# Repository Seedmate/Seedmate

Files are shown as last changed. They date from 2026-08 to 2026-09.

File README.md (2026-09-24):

# SeedMate

SeedMate is a PIC32MM-based offline device for generating, loading, transforming, splitting, merging, displaying, and exporting BIP39-compatible seed data.

www.seedmate.net

Status: Tested and production-ready. However, unexpected bugs may still occur.

## Features

- Offline seed handling
- Entropy capture from multiple sources and multiple conversion methods
- BIP39 word-based workflows
- SeedXOR operations
- Shamir Secret Sharing over BIP39
- BIP85 derivation
- QR export
- SD card storage/export
- TFT display and button-driven interface

## Hardware target - See HW folfer

This project targets a PIC32MM-based device with:

- TFT display
- Physical buttons
- SD card interface
- LED blinking

MCU and tools:

- MCU: `PIC32MM0064GPL028`
- Toolchain: `XC32 v4.60`
- IDE / generated files: `MPLAB X / Harmony`

## Project structure

```text
src/
  main.c
  SPI.*
  TFT.*
  SHA256.*
  SHA512.*
  words.h
  SSS/
  SD/
  QRCode-master/
  WjCryptLib-master/
  config/default/    

  ## Build

This project is intended to be built with Microchip tools.

### Requirements

- MPLAB X

- XC32 compiler

- PIC32MM device pack

- Any project-generated files required by Harmony / MPLAB

### Typical build flow

1. Open the project in MPLAB X.

2. Select the correct configuration.

3. Build the project with XC32.

4. Flash the generated firmware to the target board. A Microchip programmer tool is required:
https://www.microchip.com/en-us/development-tool/pg164130

## Programming instructions / firmware update
See https://www.seedmate.net/FW_update.html

## Usage notes

- This device is designed to work offline 

- Do not use phones, cloud notes, or networked systems to store sensitive seed material.

- Review the full workflow yourself before trusting it with real funds.

- Treat QR and SD export paths as sensitive.

- See Security Risks & Guidelines https://www.seedmate.net/security.html

## Security warning

This project handles highly sensitive cryptographic material.

This repository is provided for development, educational, and commercial applications unless explicitly stated otherwise.

## Third-party components

This project includes or references third-party code. See:

- THIRD_PARTY_NOTICES.md

## Roadmap / pending cleanup

## License

This project is licensed under the MIT License.

MIT License

Copyright (c) 2026 Seedmate

Permission is hereby granted, free of charge, to any person obtaining a copy
of this software and associated documentation files (the "Software"), to deal
in the Software without restriction, including without limitation the rights
to use, copy, modify, merge, publish, distribute, sublicense, and/or sell
copies of the Software, and to permit persons to whom the Software is
furnished to do so, subject to the following conditions:

The above copyright notice and this permission notice shall be included in all
copies or substantial portions of the Software.

THE SOFTWARE IS PROVIDED "AS IS", WITHOUT WARRANTY OF ANY KIND, EXPRESS OR
IMPLIED, INCLUDING BUT NOT LIMITED TO THE WARRANTIES OF MERCHANTABILITY,
FITNESS FOR A PARTICULAR PURPOSE AND NONINFRINGEMENT. IN NO EVENT SHALL THE
AUTHORS OR COPYRIGHT HOLDERS BE LIABLE FOR ANY CLAIM, DAMAGES OR OTHER
LIABILITY, WHETHER IN AN ACTION OF CONTRACT, TORT OR OTHERWISE, ARISING FROM,
OUT OF OR IN CONNECTION WITH THE SOFTWARE OR THE USE OR OTHER DEALINGS IN THE
SOFTWARE.

## Author

Seedmate

## Disclaimer

Use at your own risk. The authors provide no warranty of correctness, fitness, or security.

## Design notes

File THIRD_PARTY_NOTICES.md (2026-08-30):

**THIRD_PARTY_NOTICES.md**
```md
# Third-Party Notices

This project includes, vendors, or references third-party components.

## Important

## 1. WjCryptLib

- **Directory:** `src/WjCryptLib-master/`
- **Project:** `WjCryptLib`
- **Upstream:** `https://github.com/WaterJuice/WjCryptLib`
- **Used for:** SHA256 for checksum calculation
- **Used for:** SHA512 for BIP85 derivation
- **License:** `UNLICENSE`
- **Copyright:** `Public Domain (Author: WaterJuice)`

---

## 2. QRCode library

- **Directory:** `src/QRCode-master/`
- **Project:** `QRCode`
- **Upstream:** `https://github.com/ricmoo/QRCode`
- **Used for:** QR code generation
 * Copyright (c) 2017 Richard Moore     (https://github.com/ricmoo/QRCode)
 * Copyright (c) 2017 Project Nayuki    (https://www.nayuki.io/page/qr-code-generator-library)
 *
 * Permission is hereby granted, free of charge, to any person obtaining a copy
 * of this software and associated documentation files (the "Software"), to deal
 * in the Software without restriction, including without limitation the rights
 * to use, copy, modify, merge, publish, distribute, sublicense, and/or sell
 * copies of the Software, and to permit persons to whom the Software is
 * furnished to do so, subject to the following conditions:
 *
 * The above copyright notice and this permission notice shall be included in
 * all copies or substantial portions of the Software. 

## 3. Shamir Secret Share

- **Directory / file:** `src/SSS`
- **Project:** `trezor-firmware`
- **Upstream:** `https://github.com/trezor/trezor-firmware/blob/main/crypto/`
- **Used for:** `Shamir arithmetics`
 * Implementation of the hazardous parts of the SSS library
 *
 * Copyright (c) 2017 Daan Sprenkels <hello@dsprenkels.com>
 * Copyright (c) 2019 SatoshiLabs
 *
 * Permission is hereby granted, free of charge, to any person obtaining
 * a copy of this software and associated documentation files (the "Software"),
 * to deal in the Software without restriction, including without limitation
 * the rights to use, copy, modify, merge, publish, distribute, sublicense,
 * and/or sell copies of the Software, and to permit persons to whom the
 * Software is furnished to do so, subject to the following conditions:
 *
 * The above copyright notice and this permission notice shall be included
 * in all copies or substantial portions of the Software.

## 4. Microchip-generated or Microchip-provided code

- **Directories / files:**  
  - `src/config/default/`
  - generated startup / peripheral / Harmony-related files
- **Provider:** Microchip Technology Inc.
- **Upstream:** MPLAB X / Harmony / device pack generated content
- **Used for:** platform initialization, peripheral support, device integration
- **License:** `Microchip Restricted License`
- **Copyright:** 2025 Microchip Technology Inc. and its subsidiaries.

---

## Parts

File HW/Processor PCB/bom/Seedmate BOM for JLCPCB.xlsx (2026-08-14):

Comment | Designator | Footprint | Quantity | JLCPCB Part #（optional）
Cap Ceramic 0.1uF 10V X5R 10% SMD 0402 85C Paper T/R | C1, C4, C5, C6, C8, C9 | GRM152R61A104KE19D | 6 | C1525
CAP CER 10UF 25V X5R 0805 | C2, C3, C7, C11 | GRM21BR61E106KA73K | 4 | C15850
CAP CER 470PF 50V X7R 0603 | C10 | C0603C471K5RACTU | 1 | C1620
Diode green | D1 | DY-332SUGD-A3 | 1 | C7470788
Diode blue | D2 | DY-333YD-SN-A3(EL) | 1 | C7470788
Battery holder | J2 | BH-AAA-B5AA005 | 1 | C2979170
push buttons | SW2, SW3, SW4, SW5, SW6, SW7 | K2-6639SP-J4SC-04 | 6 | C191623
RES SMD 10K OHM 1% 1/10W 0603 | R1 | CRCW060310K0FKEA | 1 | C25804
RES SMD 1K OHM 1% 1/10W 0603 | R2 | CRCW06031K00FKEA | 1 | C21190
RES 1K2 OHM 1/8W 1% SMD 0805 | R3, R4 |  | 2
SPDT 300mA 6V | SW1 | K3-1280S-F1 | 1 | C92658
PIC processor | U1 | PIC32MM0064GPL028-ISS | 1 | C81795
IC REG LINEAR 3.3V 500MA SOT23-5 | U2 | MIC5219-3.3YM5-TR | 1 | C29613
1 1x4P 2.54mm 4P Plugin,P=2.54mm Pin Headers ROHS | J3 | 2.54-1*4 | 1 | C5116483

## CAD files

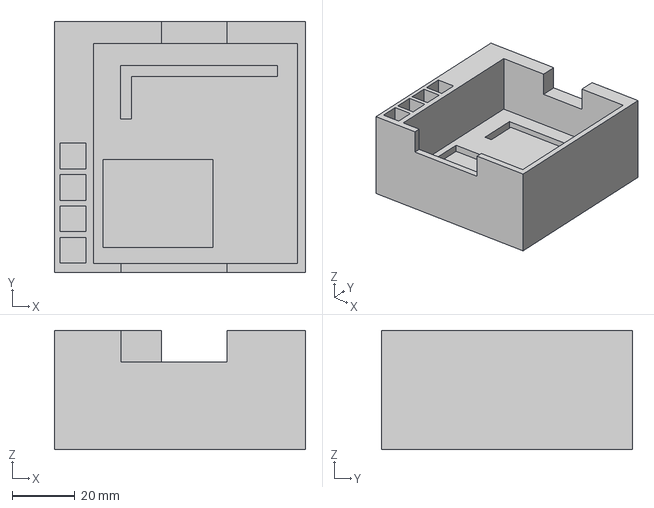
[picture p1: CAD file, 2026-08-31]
HW/Assembly/3D/package.step
80.0 x 80.0 x 38.0 mm

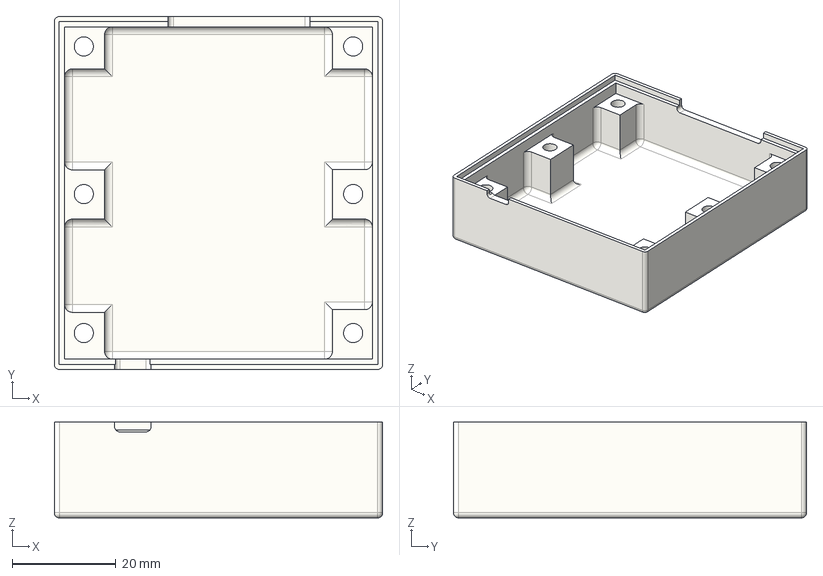
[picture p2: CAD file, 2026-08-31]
HW/Assembly/3D/case_bottom.step
63.4 x 68.2 x 18.5 mm

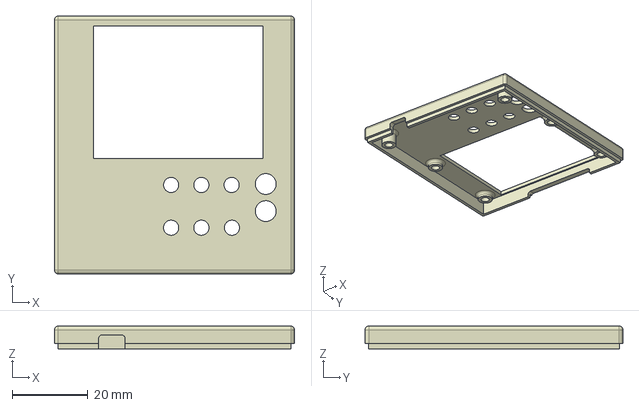
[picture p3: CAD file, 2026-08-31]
HW/Assembly/3D/case_top.step
63.4 x 68.2 x 6.05 mm

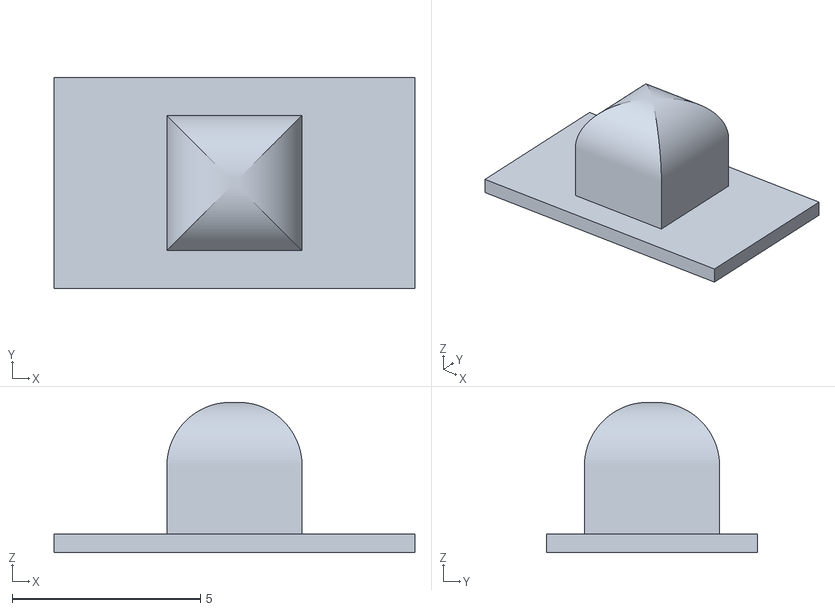
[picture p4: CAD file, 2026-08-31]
HW/Assembly/3D/slide button.stl
9.60 x 5.60 x 4.00

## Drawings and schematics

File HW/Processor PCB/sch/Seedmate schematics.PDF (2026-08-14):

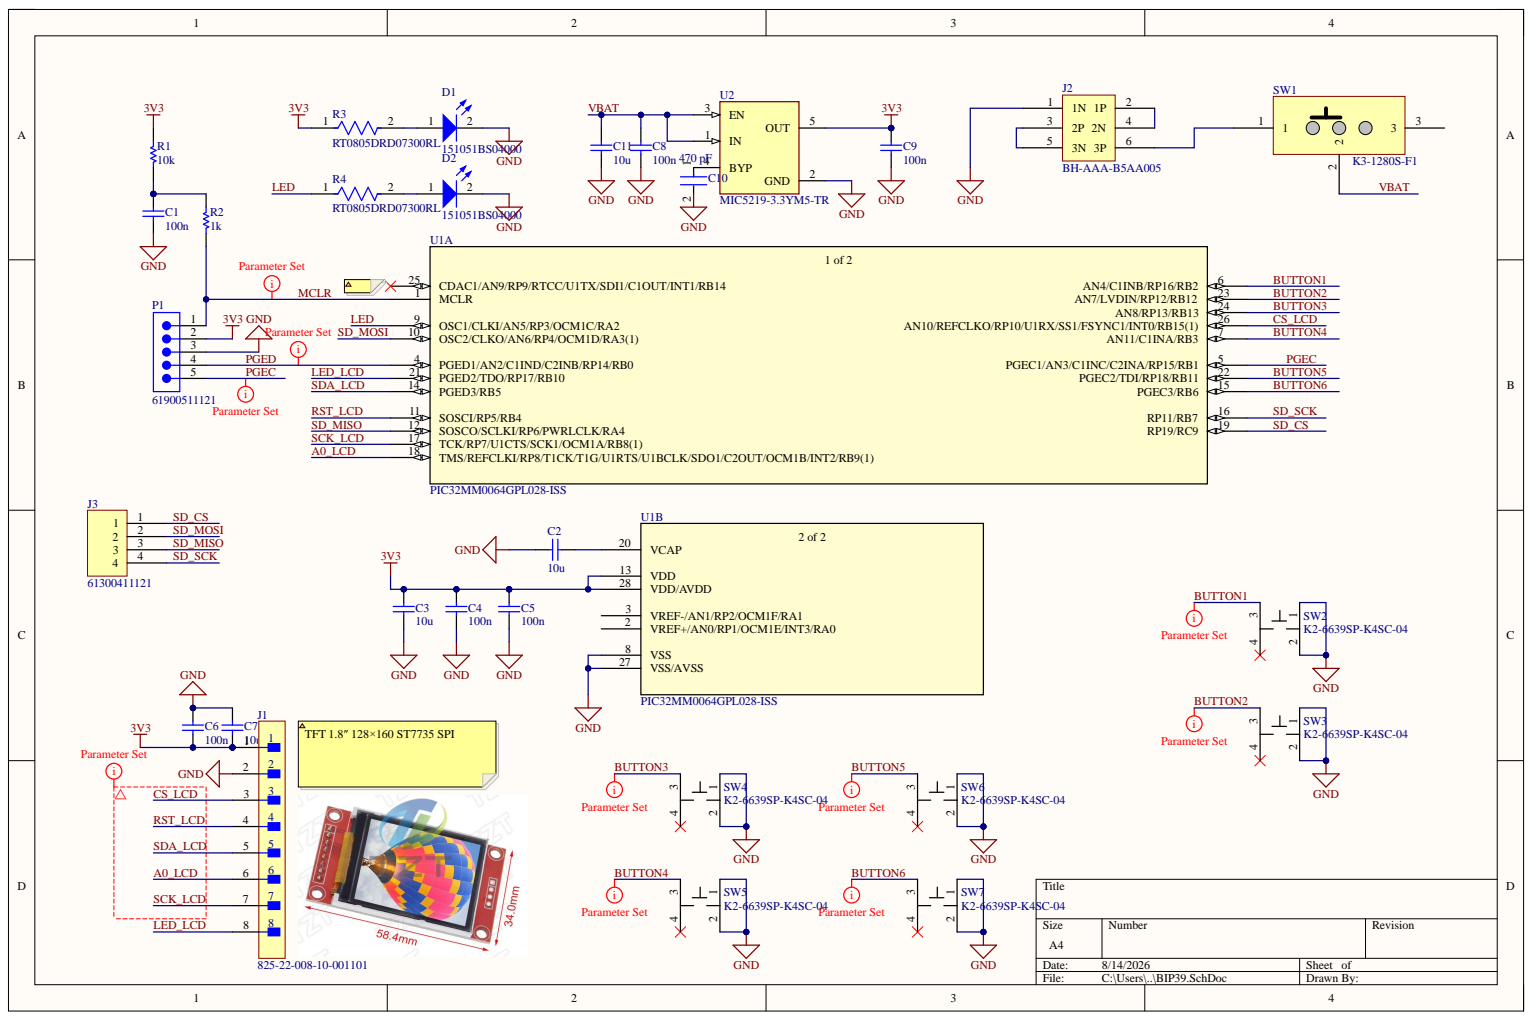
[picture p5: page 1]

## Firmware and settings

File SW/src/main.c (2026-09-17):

/*******************************************************************************
 * Project:     SeedMate
 * File:        main.c
 *
 * Summary:
 *   Main application entry point for the SeedMate firmware.
 *
 * Description:
 *   This firmware runs on a PIC32MM-based platform with TFT display, buttons,
 *   SD card support, QR generation, and entropy capture features. It provides
 *   an offline workflow to create, load, transform, split, merge, display,
 *   and export BIP39-compatible seed data.
 *
 * Main responsibilities:
 *   - Initialize hardware and application services
 *   - Handle user input and screen navigation
 *   - Capture entropy from supported input sources
 *   - Manage seed generation and validation
 *   - Support XOR and Shamir-based operations
 *   - Export data through QR and SD card features
 *
 * Notes:
 *   - This project is intended for offline use
 *   - Security-sensitive data should be handled carefully at all times
 *
 * Author:      Seedmate
 * Date:        17/09/2026
 * Version:     v1.7                               
 * License
 * 
 * This project is licensed under the MIT License.
 * 
 * MIT License
 * 
 * Copyright (c) 2026 Seedmate
 * 
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
 * THE SOFTWARE IS PROVIDED "AS IS", WITHOUT WARRANTY OF ANY KIND, EXPRESS OR
 * IMPLIED, INCLUDING BUT NOT LIMITED TO THE WARRANTIES OF MERCHANTABILITY,
 * FITNESS FOR A PARTICULAR PURPOSE AND NONINFRINGEMENT. IN NO EVENT SHALL THE
 * AUTHORS OR COPYRIGHT HOLDERS BE LIABLE FOR ANY CLAIM, DAMAGES OR OTHER
 * LIABILITY, WHETHER IN AN ACTION OF CONTRACT, TORT OR OTHERWISE, ARISING FROM,
 * OUT OF OR IN CONNECTION WITH THE SOFTWARE OR THE USE OR OTHER DEALINGS IN THE
 * SOFTWARE.
 ******************************************************************************/

// *****************************************************************************
// *****************************************************************************
// Section: Included Files
// *****************************************************************************
// *****************************************************************************

#include <stddef.h>                     // Defines NULL
#include <stdbool.h>                    // Defines true
#include <stdlib.h>                     // Defines EXIT_FAILURE
#include "definitions.h"                // SYS function prototypes
#include "SPI.h"                        // SPI functions
#include "TFT.h"                        // TFT functions
#include "sha256.h"
#include "sha512.h"
//#include "screens.h"
#include "words_opt.h"
#include <string.h>
#include "SSS/shamir.h"
#include "QRCode-master/src/qrcode.h"
#define QR_SCALE 4 // Size of each module in pixels
#define SCREEN_WIDTH 160
#define SCREEN_HEIGHT 128


#define cVersion "v1.7"

#define SD_SCK    PORTBbits.RB7
#define SD_CS     PORTCbits.RC9
#define SD_MISO   PORTAbits.RA4
#define SD_MOSI   PORTAbits.RA3

// Pin mapping
#define LED       PORTAbits.RA2   // CPU activity led

// LCD
#define LED_LCD   PORTBbits.RB10  // TFT backlight control

// Buttons
#define BT1       PORTBbits.RB2   // Button 1
#define BT2       PORTBbits.RB12  // Button 2
#define BT_OK     PORTBbits.RB13  // Button 3
#define BT4       PORTBbits.RB3   // Button 4
#define BT5       PORTBbits.RB11  // Button 5
#define BT6       PORTBbits.RB6   // Button 6


#define cMAIN_n_opt 10
#define cSEED_n_opt 6
#define cSIZE_n_opt 2
#define cOBFUS_n_opt 5
#define cXOR_n_opt 3
#define cSSS_n_opt 2
#define cQR_n_opt 2
#define cSDBLOCK_n_opt 8
#define cSELINPUT_n_opt 2
#define cDICE_MODE_n_opt 2
#define cHASH_MODE_n_opt 2
#define cRESOURCE_n_opt 5
#define cSETTINGS_n_opt 1
#define cSETTINGS_SEEDQR 0
#define cEND_OF_LINE 150
#define cENTROPY_BITS12W 127
#define cENTROPY_BITS24W 255
#define cCARD_MAX_HISTORY 128

bool seedqr_enabled = false;
int settings_pointer = 0;


#define cMAIN_create 0
#define cMAIN_LOAD 1
#define cMAIN_BIP85 2
#define cMAIN_SSS 3
#define cMAIN_XOR 4
#define cMAIN_OBFUS 5
#define cMAIN_MNEM2CARD 6
#define cMAIN_ERASESD 7
#define cMAIN_QR 8 // Resources menu
#define cMAIN_SETTINGS 9

#define cRESOURCE_tutorial 0
#define cRESOURCE_backup 1
#define cRESOURCE_dice_test 2
#define cRESOURCE_wordlist 3
#define cRESOURCE_BINlist 4

#define cOBFUS_SHIFT 0
#define cOBFUS_NOT 1
#define cOBFUS_ADD 2
#define cOBFUS_1WORD_XOR 3
#define cOBFUS_HOWTO 4

#define cSEED_coin 0
#define cSEED_dice 1
#define cSEED_word 2
#define cSEED_cards 3
#define cSEED_timer 4
#define cSEED_triple 5


#define cSIZE_12 0
#define cSIZE_24 1

#define cKEYBOARD 0
#define cFROMSD 1
#define cSD_CHECKSUM_ADDR 64
#define cSD_SIZE_ADDR 65
#define cSD_XOR_ADDR 66 // Key storage offset

#define cLEFT 0
#define cRIGTH 1

#define cADD 0
#define cSUB 1

#define cNOTSAFE 0
#define cSAFE 1

#define cREAD 0
#define cWRITE 1

#define cQRCOMPACT 1

#define  cSPLIT 0
#define  cMERGE 1

// SSS limits
#define  cK_MAX 6 // Max 6th order polynomial
#define  cN_MAX 9 // Max 9 samples

#define INCORRECT_MSG "INCORRECT SET OF WORDS"
#define LOAD_OK "LOAD OK"
#define OK_MSG "OK"

#define SHA512_SIZE 64          // SHA512 output size
#define BLOCK_SIZE 128 // SHA512 block size

// ============================================================================
// Global Menus (Forces the compiler to store pointers strictly in ROM)
// ============================================================================
const char* const menu_main[]     = {"CREATE NEW SEED WORDS", "LOAD SEED WORDS", "BIP85 CHILD SEED", "SHAMIR SECRET SHARE", "SEED WORD XOR", "OBFUSCATION", "MNEMONIC TO CARDS", "ERASE SD", "RESOURCES", "SETTINGS"};
const char* const menu_create[]   = {"THROW COINS", "ROLL DICE", "RANDOM WORD PICK", "DRAW CARDS", "STOPWATCH TEST ONLY", "TRIPLE MNEMONIC"};
const char* const menu_dice[]     = {"RAW ENTROPY BITS", "STRING HASH"};
const char* const menu_hash[]     = {"1-6 mode", "0-5 mode (Keystone)"};
const char* const menu_size[]     = {"12 WORDS", "24 WORDS"};
const char* const menu_qr[]       = {"STANDARD", "COMPACT"};
const char* const menu_xor[]      = {"A XOR B = C", "A XOR B XOR C = D", "A XOR B XOR C XOR D = E"};
const char* const menu_sss[]      = {"SPLIT", "MERGE"};
const char* const menu_input[]    = {"FROM KEYBOARD", "FROM SD"};
const char* const menu_resource[] = {"TUTORIAL", "BACKUP TOOL", "DICE TESTER", "PRINT WORDLIST", "BINARY WORDLIST"};
const char* const menu_obfus[]    = {"CIRCULAR SHIFT", "NOT OPERATOR", "WORDS ADD/SUB","1 WORD XOR","HOW TO"}; 


int main_pointer = 0;
int obfuscation_pointer =0;
int sss_pointer = 0;
int resource_pointer = 0;
uint8_t  selected_share_id = 1;
int shares_loaded = 0;

int bip85_size = cSIZE_12;
int bip85_index = 0;
int bip85_cursor = 0;

// XOR Globals moved from main()
int xor_pointer = 0;
BYTE xor_merge_word1[32] = {0};
BYTE xor_merge_word2[32] = {0};
BYTE xor_merge_word3[32] = {0};
int xor_merge_words_available = 0;

int extract_word_offset = 0;
int triple_view_state = 0;
BYTE triple_backup_256b[36] = {0};

int dice_x_pointer = 0;
int dice_y_pointer = 25;

int dice_mode_pointer = 0;
int hash_mode_pointer = 0;

#define char_hash_limit 501
#define c12_rolls 50
#define c24_rolls 99
char dice_string_buf[char_hash_limit] = {0};
int dice_input_idx = 0; // 0-5 for '1'-'6', 6 for DONE

BYTE data_array_256b[36] = {0}; // Increased buffer size to handle excess bits tracking
int size_pointer = 0;
int bit_count_dice = 0;
int entropy_bits = 0;
int last_input_len = 0; // Tracks the length of the most recent entropy input

bool capturing_xor_word = false; // Flag to hijack WRITE_WORD behavior
int obfus_xor_word_idx = 0;

int seed_pointer = 0;
int card_rank_pointer = 0;
int card_suit_pointer = 0;
int card_field_pointer = 0;
int card_history_count = 0;
uint16_t card_history_start_bits[cCARD_MAX_HISTORY] = {0};
uint8_t card_history_bit_len[cCARD_MAX_HISTORY] = {0};


const char card_rank_chars[13] = { 'a', '2', '3', '4', '5', '6', '7', '8', '9', 't', 'j', 'q', 'k' };
const char card_suit_chars[4] = { 'c', 'd', 'h', 's' };
const char * const card_entropy_map[52] = {
    "00000", "00001", "00010", "00011", "00100", "00101", "00110", "00111", "01000", "01001", "01010", "01011", "01100",
    "01101", "01110", "01111", "10000", "10001", "10010", "10011", "10100", "10101", "10110", "10111", "11000", "11001",
    "11010", "11011", "11100", "11101", "11110", "11111", "0000",  "0001",  "0010",  "0011",  "0100",  "0101",  "0110",
    "0111",  "1000",  "1001",  "1010",  "1011",  "1100",  "1101",  "1110",  "1111",  "00",    "01",    "10",    "11"
};

#define NCOEFF 5
#define BYTES_PER_COEFF 32 // Same as LEN
#define TOTAL_BYTES (NCOEFF * BYTES_PER_COEFF)

uint8_t c0[BYTES_PER_COEFF] = { 0 };  // len = 1
uint8_t c1[BYTES_PER_COEFF] = { 0 };
uint8_t c2[BYTES_PER_COEFF] = { 0 };
uint8_t c3[BYTES_PER_COEFF] = { 0 };
uint8_t c4[BYTES_PER_COEFF] = { 0 };


int coeff_byte_idx = 0;

// Pointer table to avoid a switch
uint8_t * const coefficient_buffers[5] = { c0, c1, c2, c3, c4 };
static void u16_to_hex4(uint16_t value, char *buf);
static size_t u16_to_str(unsigned int n, char *buf);
static size_t u16_to_str_pad(unsigned int n, char *buf, unsigned int width);
static void clear_string(char *text);
static void remove_last_char(char *text);
static char *add_char(char *text, int letter_index, size_t capacity);
static char *add_char_dice(char *text, int num, size_t capacity);
static const char *search_unique_prefix(const char *prefix, char *result, size_t result_size);
static BYTE *append_checksum(BYTE *data_array, int N);
static void write_11bit_value(BYTE *buffer, int index, int value);
static bool matches_last_word_checksum(BYTE *data_array, char *word_user, int sel_size);

static void shift_left(BYTE *data, int N);
static void shift_right(BYTE *data, int N);
static void not_operator(BYTE *data, int N);
void black_screen(void);
void set_bit(BYTE data_array[36], int bit_index, int value);
const char* get_confirmed_word_from_entropy(const BYTE data_array[36], int index);
int read_11bit_value(const BYTE data_array[36], int index);
void print_checksum_screen(void);
void print_word_number_top(int word_number, char *word_number_text);
void print_triple_checksum(int word_target);
const char* get_word(int index);
int get_next_valid_key(int current_idx, int step, const char *current_word, bool ok_is_valid);
int get_nearest_valid_key(int current_idx, const char *current_word, bool ok_is_valid);

// Advanced screen redraw logic to seal memory leak and handle navigation states natively
void redraw_show_seed_with_offset(void);
void refresh_triple_view(void);
void extract_11bit_groups(BYTE *data, size_t size);

// Prototypes for smart keyboard prediction
static void get_valid_next_letters(const char *prefix, bool *valid_letters);
void print_keyboard_with_validation(int index, bool word_found, const char *current_word);

// Mnemonic to Cards Globals
uint8_t card_sequence[132];
int card_sequence_len = 0;
int card_decks_needed = 0;
int card_view_page = 0;


// ============================================================================
// BIP85 Derivation Engine
// ============================================================================
// -------------------- HMAC-SHA512 --------------------

void HmacSha512(const BYTE *key, size_t keyLen,
                const BYTE *data, size_t dataLen,
                BYTE *out) {
    BYTE k_ipad[BLOCK_SIZE];
    BYTE k_opad[BLOCK_SIZE];
    SHA512_HASH innerHash;
    SHA512_HASH outerHash;
    Sha512Context ctx;

    if (keyLen > BLOCK_SIZE) {
        Sha512Initialise(&ctx);
        Sha512Update(&ctx, key, keyLen);
        Sha512Finalise(&ctx, &innerHash);
        key = innerHash.bytes;
        keyLen = SHA512_SIZE;
    }

    memset(k_ipad, 0x36, BLOCK_SIZE);
    memset(k_opad, 0x5c, BLOCK_SIZE);

    for (size_t i = 0; i < keyLen; i++) {
        k_ipad[i] ^= key[i];
        k_opad[i] ^= key[i];
    }

    // Inner hash
    Sha512Initialise(&ctx);
    Sha512Update(&ctx, k_ipad, BLOCK_SIZE);
    Sha512Update(&ctx, data, dataLen);
    Sha512Finalise(&ctx, &innerHash);

    // Outer hash
    Sha512Initialise(&ctx);
    Sha512Update(&ctx, k_opad, BLOCK_SIZE);
    Sha512Update(&ctx, innerHash.bytes, SHA512_SIZE);
    Sha512Finalise(&ctx, &outerHash);

    memcpy(out, outerHash.bytes, SHA512_SIZE);
}
// -------------------- PBKDF2-HMAC-SHA512 --------------------
void PBKDF2_HMAC_SHA512(const char *password, const char *salt,
                        uint32_t iterations, BYTE *output, size_t dkLen) {
    uint32_t blockCount = (dkLen + SHA512_SIZE - 1) / SHA512_SIZE;
    BYTE U[SHA512_SIZE];
    BYTE T[SHA512_SIZE];
    BYTE saltBlock[32]; 
    size_t saltLen = strlen(salt);

    for (uint32_t i = 1; i <= blockCount; i++) {
        memcpy(saltBlock, salt, saltLen);
        saltBlock[saltLen + 0] = (i >> 24) & 0xFF;
        saltBlock[saltLen + 1] = (i >> 16) & 0xFF;
        saltBlock[saltLen + 2] = (i >> 8) & 0xFF;
        saltBlock[saltLen + 3] = i & 0xFF;

        HmacSha512((const BYTE *)password, strlen(password),
                   saltBlock, saltLen + 4, U);
        memcpy(T, U, SHA512_SIZE);

        for (uint32_t j = 2; j <= iterations; j++) {
            HmacSha512((const BYTE *)password, strlen(password),
                       U, SHA512_SIZE, U);
            for (int k = 0; k < SHA512_SIZE; k++) {
                T[k] ^= U[k];
            }
            
            // Keep the system and watchdog happy during the heavy hash loop
            if (j % 16 == 0) {
                SYS_Tasks(); 
            }
            
            // Simple UI Progress Bar 
            if (j % 102 == 0) {
                int chunk = j / 102; // Yields 1 through 20
                rectan(20 + (chunk * 5), 70, 24 + (chunk * 5), 80, ST7735_GREEN);
            }
        }

        size_t offset = (i - 1) * SHA512_SIZE;
        size_t toCopy = (dkLen - offset < SHA512_SIZE) ? (dkLen - offset) : SHA512_SIZE;
        memcpy(output + offset, T, toCopy);
    }
}
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
int main ( void ){
    /* Initialize all modules */
    SYS_Initialize ( NULL );
    R_LCD=1;
    LED_LCD =1;
    A0_LCD=0;
    LED = 0;
    SPI1CON= 0x10000120;
    SPI1CON= 0x10008120;
    SPI1BRG= 1;
    LED_LCD =1;
    SD_CS =1;


    LCDinit1();
    black_screen();
    LCDinit2();
    black_screen();

    print_logo();
    drawtext(1,40, "KEEP YOUR SEEDS OFFLINE", ST7735_GREEN, ST7735_BLACK, 1);
    drawtext(1,51, "NO PHONE PHOTOS/QR", ST7735_RED, ST7735_BLACK, 1);
    drawtext(1,62, "SD AWAY FROM A COMPUTER", ST7735_RED, ST7735_BLACK, 1);
    print_camera(5,95,cSAFE);
    drawtext(23,87, "=QR Safe for phone", ST7735_GREEN, ST7735_BLACK, 1);
    print_camera(5,110,cNOTSAFE);
    drawtext(23,102, "=QR NOT Safe for phone", ST7735_RED, ST7735_BLACK, 1);
    drawtext(5,119, "(Press any button)", ST7735_WHITE, ST7735_BLACK, 1);
    version_display();

    PULSED_BT_t pulsed_bt = NONE;

    // Initialize the SD card only once at startup.
    SD_ready = sd_init();
    tmr1_init();



    int BT1_ST= 1;
    int BT2_ST= 1;
    int BT_OK_ST = 1;
    int BT4_ST= 1;
    int BT5_ST= 1;
    int BT6_ST= 1;

    int SSS_K = 2;
    int SSS_N = 9;
    int sel_K_N = 0;
    int SDblock_pointer = 0;
    int selinput_pointer = 0;

    uint16_t time_now ;

    //BYTE checksum_SD =0;
    BYTE XOR_SD =0;

    int lt_idx = 0; // Letter index

    char word[32] = {0};
    char result[32]; // Search result preview
    const char* found = NULL;
    bool found_bool = false;

    word[0] = '\0';

    int word_number = 1; // Tracks the word being entered
    char word_number_text[12];

    const size_t LEN = 32;

    uint8_t SSS_result[LEN];

    const uint8_t *coeffs[cK_MAX-1] = { c0, c1, c2, c3, c4 }; // Maximum polynomial degree 6
    uint8_t sh1[LEN], sh2[LEN], sh3[LEN], sh4[LEN], sh5[LEN], sh6[LEN], sh7[LEN], sh8[LEN], sh9[LEN];
    uint8_t *shares[cN_MAX] = {sh1, sh2, sh3, sh4, sh5, sh6, sh7, sh8, sh9};

    // Buffers used while reconstructing shares.
    uint8_t *shares_input[cN_MAX] = {sh1, sh2, sh3, sh4, sh5, sh6, sh7, sh8, sh9};
    uint8_t share_indices[cK_MAX] = { 1, 2,0,0,0,0 };

    while ( true )
    {
        /* Maintain state machines of all polled MPLAB Harmony modules. */
        SYS_Tasks ( );

        // Button pressing logic
        if ((BT_OK ==0) & (BT_OK_ST==1)) {
            LED = 1;
            update_entropy_coefficients(); // Capture fresh coefficient bytes on each press
            delay_ms(30);
            LED = 0;
            if (BT_OK ==0) {
                BT_OK_ST=0;
                pulsed_bt = OK_BT;
                }
         }  else if ((BT1 ==0) & (BT1_ST==1)) {
            LED = 1;
            update_entropy_coefficients();
            delay_ms(30);
            LED = 0;
            if (BT1 ==0) {
                BT1_ST=0;
                pulsed_bt = BACK_BT;
                }
         }  else if ((BT2 ==0) & (BT2_ST==1)) {
            LED = 1;
            update_entropy_coefficients();
            delay_ms(30);
            LED = 0;
            if (BT2 ==0) {
                BT2_ST=0;
                pulsed_bt = LEFT_BT;
                }
         }  else if ((BT4 ==0) & (BT4_ST==1)) {
            LED = 1;
            update_entropy_coefficients();
            delay_ms(30);
            LED = 0;
            if (BT4 ==0) {
                BT4_ST=0;
                pulsed_bt = DOWN_BT;
                }
         }  else if ((BT5 ==0) & (BT5_ST==1)) {
            LED = 1;
            update_entropy_coefficients();
            delay_ms(30);
            LED = 0;
            if (BT5 ==0) {
                BT5_ST=0;
                pulsed_bt = UP_BT;
                }
         }  else if ((BT6 ==0) & (BT6_ST==1)) {
            LED = 1;
            update_entropy_coefficients();
            delay_ms(30);
            LED = 0;
            if (BT6 ==0) {
                BT6_ST=0;
                pulsed_bt = RIGTH_BT;
                }
        } else {
            if (BT_OK ==1){
            BT_OK_ST=1;
            }
            if (BT1 ==1){
            BT1_ST=1;
            }
            if (BT2 ==1){
            BT2_ST=1;
            }
            if (BT4 ==1){
            BT4_ST=1;
            }
            if (BT5 ==1){
            BT5_ST=1;
            }
            if (BT6 ==1){
            BT6_ST=1;
            }
        }
        // End button pressing logic


        // STATE MACHINE
        switch (estado) {

            case INIT:
                switch (pulsed_bt) {
                    case OK_BT:
                    case BACK_BT:
                    case UP_BT:
                    case DOWN_BT:
                    case LEFT_BT:
                    case RIGTH_BT:
                        transition_to_main();
                        break;
                    default:
                        break;
                }
                break;

            case MAIN:
                switch (pulsed_bt) {
                    case OK_BT:
                        black_screen();
                        if (main_pointer==cMAIN_create){// Create new seed
                            transition_to_create_seed();
                        } else if (main_pointer==cMAIN_LOAD ){// Load seed words
                            transition_to_input(selinput_pointer);
                        } else if (main_pointer == cMAIN_BIP85) { // BIP85 child seed
                            
                            print_child_config_screen();
                            estado = CHILD_CONFIG;
                        } else if (main_pointer==cMAIN_XOR){// XOR
                            
                            print_generic_menu(menu_xor, cXOR_n_opt, xor_pointer);
                            estado = SEL_XOR;
                        } else if (main_pointer==cMAIN_OBFUS){// Obfuscation
                            transition_to_obfus();
                        } else if (main_pointer==cMAIN_MNEM2CARD){// Convert to Cards
                            transition_to_input(selinput_pointer);
                        } else if (main_pointer==cMAIN_SSS){// Shamir
                           
                            print_generic_menu(menu_sss, cSSS_n_opt, sss_pointer);
                            estado = SEL_SSS;
                        } else if (main_pointer==cMAIN_ERASESD){// Erase SD
                            transition_to_sd_block(SDblock_pointer);
                        } else if (main_pointer==cMAIN_QR){// Resources menu
                           
                            print_generic_menu(menu_resource, cRESOURCE_n_opt, resource_pointer);
                            estado = RESOURCE_MENU;
                        } else if (main_pointer == cMAIN_SETTINGS) {
                           
                            print_settings_screen(settings_pointer);
                            estado = SEL_SETTINGS;                        
                        }
                        break;
                    case BACK_BT:
                        break;
                    case UP_BT:
                        spi_send(0x33);
                        if (main_pointer > 0) {
                            main_pointer--;
                        }
                        main_screen(main_pointer); // <--- Actualizado
                        break;
                    case DOWN_BT:
                        spi_send(0x55);
                        if (main_pointer < (cMAIN_n_opt-1)) {
                            main_pointer++;
                        }
                        main_screen(main_pointer); // <--- Actualizado
                        break;
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

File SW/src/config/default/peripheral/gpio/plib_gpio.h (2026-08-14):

/*******************************************************************************
  GPIO PLIB

  Company:
    Microchip Technology Inc.

  File Name:
    plib_gpio.h

  Summary:
    GPIO PLIB Header File

  Description:
    This library provides an interface to control and interact with Parallel
    Input/Output controller (GPIO) module.

*******************************************************************************/

/*******************************************************************************
* Copyright (C) 2019 Microchip Technology Inc. and its subsidiaries.
*
* Subject to your compliance with these terms, you may use Microchip software
* and any derivatives exclusively with Microchip products. It is your
* responsibility to comply with third party license terms applicable to your
* use of third party software (including open source software) that may
* accompany Microchip software.
*
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
* IN NO EVENT WILL MICROCHIP BE LIABLE FOR ANY INDIRECT, SPECIAL, PUNITIVE,
* INCIDENTAL OR CONSEQUENTIAL LOSS, DAMAGE, COST OR EXPENSE OF ANY KIND
* WHATSOEVER RELATED TO THE SOFTWARE, HOWEVER CAUSED, EVEN IF MICROCHIP HAS
* BEEN ADVISED OF THE POSSIBILITY OR THE DAMAGES ARE FORESEEABLE. TO THE
* FULLEST EXTENT ALLOWED BY LAW, MICROCHIP'S TOTAL LIABILITY ON ALL CLAIMS IN
* ANY WAY RELATED TO THIS SOFTWARE WILL NOT EXCEED THE AMOUNT OF FEES, IF ANY,
* THAT YOU HAVE PAID DIRECTLY TO MICROCHIP FOR THIS SOFTWARE.
*******************************************************************************/

#ifndef PLIB_GPIO_H
#define PLIB_GPIO_H

#include <device.h>
#include <stdint.h>
#include <stdbool.h>
#include <stddef.h>

// DOM-IGNORE-BEGIN
#ifdef __cplusplus  // Provide C++ Compatibility

    extern "C" {

#endif
// DOM-IGNORE-END

// *****************************************************************************
// *****************************************************************************
// Section: Data types and constants
// *****************************************************************************
// *****************************************************************************


/*** Macros for ANALOG0 pin ***/
#define ANALOG0_Get()               ((PORTA >> 0) & 0x1)
#define ANALOG0_GetLatch()          ((LATA >> 0) & 0x1)
#define ANALOG0_PIN                  GPIO_PIN_RA0

/*** Macros for BT1 pin ***/
#define BT1_Set()               (LATBSET = (1<<2))
#define BT1_Clear()             (LATBCLR = (1<<2))
#define BT1_Toggle()            (LATBINV= (1<<2))
#define BT1_OutputEnable()      (TRISBCLR = (1<<2))
#define BT1_InputEnable()       (TRISBSET = (1<<2))
#define BT1_Get()               ((PORTB >> 2) & 0x1)
#define BT1_GetLatch()          ((LATB >> 2) & 0x1)
#define BT1_PIN                  GPIO_PIN_RB2

/*** Macros for BT4 pin ***/
#define BT4_Set()               (LATBSET = (1<<3))
#define BT4_Clear()             (LATBCLR = (1<<3))
#define BT4_Toggle()            (LATBINV= (1<<3))
#define BT4_OutputEnable()      (TRISBCLR = (1<<3))
#define BT4_InputEnable()       (TRISBSET = (1<<3))
#define BT4_Get()               ((PORTB >> 3) & 0x1)
#define BT4_GetLatch()          ((LATB >> 3) & 0x1)
#define BT4_PIN                  GPIO_PIN_RB3

/*** Macros for LED pin ***/
#define LED_Set()               (LATASET = (1<<2))
#define LED_Clear()             (LATACLR = (1<<2))
#define LED_Toggle()            (LATAINV= (1<<2))
#define LED_OutputEnable()      (TRISACLR = (1<<2))
#define LED_InputEnable()       (TRISASET = (1<<2))
#define LED_Get()               ((PORTA >> 2) & 0x1)
#define LED_GetLatch()          ((LATA >> 2) & 0x1)
#define LED_PIN                  GPIO_PIN_RA2

/*** Macros for SD_MOSI pin ***/
#define SD_MOSI_Set()               (LATASET = (1<<3))
#define SD_MOSI_Clear()             (LATACLR = (1<<3))
#define SD_MOSI_Toggle()            (LATAINV= (1<<3))
#define SD_MOSI_OutputEnable()      (TRISACLR = (1<<3))
#define SD_MOSI_InputEnable()       (TRISASET = (1<<3))
#define SD_MOSI_Get()               ((PORTA >> 3) & 0x1)
#define SD_MOSI_GetLatch()          ((LATA >> 3) & 0x1)
#define SD_MOSI_PIN                  GPIO_PIN_RA3

/*** Macros for R_LCD pin ***/
#define R_LCD_Set()               (LATBSET = (1<<4))
#define R_LCD_Clear()             (LATBCLR = (1<<4))
#define R_LCD_Toggle()            (LATBINV= (1<<4))
#define R_LCD_OutputEnable()      (TRISBCLR = (1<<4))
#define R_LCD_InputEnable()       (TRISBSET = (1<<4))
#define R_LCD_Get()               ((PORTB >> 4) & 0x1)
#define R_LCD_GetLatch()          ((LATB >> 4) & 0x1)
#define R_LCD_PIN                  GPIO_PIN_RB4
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

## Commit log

2026-08-14 v1.2 First github version
    [Seedmate BOM for JLCPCB.xlsx, Seedmate Pick And Place File.xlsx]
2026-08-18 Added checksum details window before displaying mnemonic list Added dice number binary equivalence on grid Entropy array increased to handle excess bits Old code cleaning Blue texts replaced with cya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
    [main.c]
2026-08-19 Triple mnemonic implemented: modify an existing 24 word to be splitable into 2x12 valid mnemonics Now displays dice icon instead of text on the grid SSS error text updated to point out that the cause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
    [main.c]
2026-08-19 Fixed navegation errors between states
    [main.c]
2026-08-20 Implemented smart keyboard Dice numbers replaced with dice icons
    [main.c]
2026-08-26 Dice hash corrections/improvements to interface
    [main.c]
2026-08-27 Max 300 dice rolls. Text does not fit the screen and it gets messy. I think I will leave it like that, 100 rolls should be ok anyway. DONE gets green from gray after 50/100 rolls
    [main.c]
2026-08-29 working on v1.5 already new main menu operation derive bip 85 child, only logic to navigate added link to printable wordlist under resources
2026-08-29 Fixed XOR logic from SD
    [main.c]
2026-08-31 Added 3D models
    [case_bottom.step, case_top.step, package.step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]
2026-09-04 Logic to prevent user from entering shame shamir share id twice delay_ms adjusted in line with the new x3 clock frequency
    [SPI.c, main.c]
2026-09-04 Obfuscation "how to" link SSS error text updated, if it ever happens it could not be caused by a repeated id
    [main.c]
2026-09-04 The actual code implementation of the last commit was missing. Also memory optimization main menu print. Screens files, lets clean the code
    [main.c]
2026-09-11 QR generation optimized: - better ECC levels for standard seedQR with the same size - sepatare methods for url strings and seedqr (numeric) - fixed a bug that made seedQR 12 words use a 29x29 instead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
    [main.c]
2026-09-14 Fix link case sensitivity in README
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2026-09-28 UARTGM861 working! cable has to be crossed manually pin by pin though
2026-10-01 Crypto operations to generate fingerprint and native segwit addresses. using trezor libraries but modifing them to use our hash methods and removing shitcoin SW etc. it seems to be wrking
2026-10-02 Revise README for toolchain and build flow clarity
    Updated toolchain version and enhanced build flow instructions.
2026-10-02 Document typical build flow in README
    Added a section detailing the typical build flow and reproducibility for the project.
2026-10-08 First bootloader working: bootloader starts in control, blinks led and jumps to main app
2026-10-19 Improved SSS coeficient generation, using SHA256 + index Verified using SSS_DEBUG deleted SD SPI debug calls
2026-10-21 Fixed a bug when loading compact seedQR Fixed a bug that prevented las row o lower case letters to be displayer. TFT.c
2026-10-21 Now BIP39 words are lower case displayed, loaded and used. As it always should have been
2026-10-22 Fixed flickerin in bip84 menu Optimized xpub and fingerprint responses Shgowing fingerprint on bip84 menu interface corrections Testing PSBT QR reading
2026-10-24 Successfully reconstruct complete PSBTs from animated QR codes using the UR fountain code standard. Note: The internal PRNG (Vose's Alias method in sampler.c) is strictly isolated and used exclusivel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
2026-10-28 Code organization to reduce main.c size. Most print functions moved to screns.c Cosntants moved app_def.h
2026-10-28 Move PSBT QR scan from startup test to BIP84 > SIGN menu PSBT viewer: show fingerprints, verified ownership, multisig and sighash
2026-10-30 XPUB QR as ur:crypto-account (BCR-2020-015) with fingerprint and origin path, readable by Sparrow. Account index in BIP84 menu (0-255, number entry, shown under fingerprint). Wallet keys derived only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
    First signed transaction broadcasted to mainnet, testnet is for pussies
    35aa83cb7bbf03fdaa428c2e13e312fc52cbdc4490f509abe3d28dcf942c6586
2026-10-30 Fast UR animated QR scan: GM861 in continuous mode during the scan only (no break, CR tail, same-code delay), interrupt-driven UART RX ring buffer, real-time timeouts with the core timer. Scanner set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
2026-10-30 Button grid (BACK / SCAN) on the QR seed load screen. THIRD_PARTY_NOTICES.md updated: all third-party code in firmware and bootloader (trezor-crypto, SSS, QRCode, SHA-256, SHA-512, Petit FatFs, Micro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
2026-10-31 Bootloader: forced SD update holding OK + BACK at power-on, UPDATE.HEX fully checked before erasing the app. Byte swap obfuscation (swaps byte pairs, undone by applying it again). Seed loaded from QR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
2026-10-31 Consistent colors: white titles, orange only for the selected item, cyan for work in progress, yellow for fee and non-blocking warnings, upper case texts (rule 7 in CLAUDE.md updated). Titles on ever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
2026-10-31 Bootloader screen: steps with progress bar, OK/BACK confirmation before erasing and the result in plain words (LED codes kept). Display driver shared with the app (TFT.c, SPI.c) and placed in free bo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
2026-10-31 Bootloader 1.0: shows the SHA-256 of UPDATE.HEX before asking to erase, and checks that what it writes is the same file (compact own SHA-256 in the free gaps of the boot flash). Refuses hex files tha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
2026-10-31 Permanent settings: DECOY GAME ON/OFF and SEEDQR ON/OFF saved in a reserved flash page (last 2 KB, 0x1D03F800) as a rotating log of 8 byte records, kept after power off and firmware updates. Each cha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
2026-11-01 Reorganize menus and SD card: SEED BACKUP, SD init, DERIVE
    Main menu now groups OPSEC and TOOLS (placeholders). Seeds are backed up
    from a SEED BACKUP menu (SD, SEEDQR, COMPACT SEEDQR) with zoomable QR
    quadrants, and the wallet menu gets DERIVE (BIP85 from the key on screen,
    passphrase included) and a VAULT placeholder.
    - SD WRITE setting, off by default, stored with the permanent settings
    - Seeds only go to slots 2..200; slot 1 stays read only; overwriting a
    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
2026-11-01 TOOLS: QR reader and QR from text with zoomable tiles
    QR READER scans one code and only shows it: a type label, the content
    in pages, binary in hex; nothing is loaded or saved. QR FROM TEXT turns
    up to 320 characters into a QR that can be zoomed tile by tile, so a
    passphrase QR can be copied by hand.
    - Raw scanner read through the UART2 interrupt ring, spaces kept
    - Text QR uses the smallest version up to 11 with ECC M, L if needed;
    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
2026-11-01 Passphrase from QR, EFF password generator
    PASSPHRASE opens a submenu: FROM KEYBOARD as before, FROM QR (shown in
    full, used only after confirmation), FROM VAULT placeholder.
    TOOLS gets EFF PASSWORD: 1-12 words of the EFF Short Wordlist 1 from dice, optional
    digits from the timer, entropy shown while configuring, result in lower
    case with a zoomable QR.
    - EFF list regenerated from the official file, host test checks SHA-256
    - Partial redraws on the EFF screens (no flicker)
2026-11-01 REVIEW PSBT tool, XPUB QR as text, UI polish
    TOOLS gets REVIEW PSBT: the signing viewer from QR or SD with no seed
    and no signing; keys are shown as not checked. The XPUB QR now defaults
    to "[fingerprint/path]xpub" text, read by Sparrow and Nunchuk, with UR
    crypto-account one key away.
    - Titles and fixed messages in light gray, data and options in white
    - Grid labels name the action (QR, SAVE, STOP, UPDT, XPUB/ZPUB)
    - Start screen back to "(PRESS ANY BUTTON)"
    - Menu entry XPUB/ZPUB, account label removed from the QR
    - SD file list redraws only what changes (no flicker)
2026-11-02 Vault groundwork: key, AES-GCM records, header at card init Start of the vault on the seed SD card (docs/vault.md, steps 1-3). - ERASE SECTOR only accepts the seed slots - BIP85 code shared in bip85.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
2026-11-02 Vault: format layer, screens, editor QR and dice keys
    The vault on the seed SD card now works from the wallet menu
    (docs/vault.md steps 4-8).
    - Format: the header records nonces before any record is written,
    every write is read back and checks the card was not swapped; the
    first counter is random so two cards never share nonces
    - VAULT screens: sorted list, new entries from templates or an EFF
    password, view with QR, edit as a new version, delete; a card
    initialized before the vault is offered an empty one
    - Editor: RETURN key split in RETURN, QR (insert a scanned text) and
    a die (insert an EFF password); EFF key handling shared with TOOLS
    - Progress screens redraw their text witho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
2026-11-02 Vault descriptors and passphrases; descriptor QR fixes
    - PASSPHRASE > FROM VAULT and IMPORT DESCRIPTOR > FROM VAULT load the
    vault's passphrase and multisig descriptor entries
    - NEW ENTRY > MULTISIG DESCRIPTOR saves a wallet scanned by QR, or the
    current one, after the same checks as IMPORT DESCRIPTOR
    - Descriptor QR: the first code is read whole, so the single part UR
    of Sparrow's PDF and plain text descriptors work; UR scans also take
    single part codes and name the codes they cannot use
    - CREATE menu entry renamed POKER CARDS
2026-11-05 Bootloader: 12 KB layout and firmware signature check
    The bootloader grows to 12 KB and verifies UPDATE.SIG (RFC 8554 LMS)
    against a test public key. Official firmware installs in green; any
    other firmware can still be installed after a red warning, and warns
    at every boot until replaced. The app keeps its code address and
    size, only its reset block moves after the vectors.
    - tools/lms_sign.html: offline page that signs UPDATE.HEX from BIP39
    words
    - Last bootloader page records the file hash and whether it was
    official; written last, so an interrupted update is not official
    - Host tests for the verifier and the new layout
2026-11-07 Save signed PSBTs to SD and redesign the PSBT review
    Replace Petit FatFs with FatFs R0.16 (FAT12/16/32, long names) so a
    signed PSBT can be written back to the card as "name-signed.psbt",
    read back and verified. The PSBT review now runs every check first,
    then shows a flow diagram, one page per output and the inputs, and
    asks to see every destination before SIGN.
    - Signed PSBT export menu: show QR or save to SD, refused on seed cards
    - Amounts in SAT under 100 000 sats, otherwise BTC; fee in ~sat/vB
    - "TYPE NOT SUPPORTED" when only taproot, nested or legacy inputs
    - Activity LED blinks during long operations
    - Script type row in WALLET CONFIG (native only for now)
    - Host tests for FatFs on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
2026-11-08 Harden PSBT checks, add high fee warning and auto unload
    Warn about what a review could miss, refuse malformed PSBTs, and
    wipe the session when the device is left alone.
    - HIGH FEE and BURNS BTC warnings on the review and confirmation
    - Parser refuses duplicate keys and malformed known fields
    - Outputs without an address shown in yellow
    - High change index warning now relative to the inputs
    - AUTO UNLOAD setting: wipe and return to the menu after 5-30 min
    - Host tests with hostile PSBTs and the BIP174 invalid vectors
2026-11-11 Add KEF iterations setting, MIX ENTROPY and hold to delete
    - SETTINGS > KEF ITERATIONS: permanent count for encrypted QR
    export, 10,000 to 300,000, with process time and protection level
    - Lighter KEF encrypt and decrypt screens, decrypt shows the time
    - CREATE > MIX ENTROPY: the XOR flow from CREATE, back to CREATE
    - Text editor: DEL held keeps deleting
2026-11-11 Fix security review findings and publish the audit with the findings of Fable 5.2
    An internal review of the firmware (docs/security-audit.md) found
    one critical, one high and several medium issues. Every input the
    device reads from outside - QR codes, SD cards, PSBTs - was treated
    as hostile. This commit fixes those that do not need a format or
    bootloader change; the rest stay listed as open in the report.
    - Critical: a crafted multisig descriptor QR (UR crypto-output that
    repeats its key list) could write past its buffer on the stack.
    The key list is now accepted once, with a regression test.
    - High: the seed size byte of an SD slot was trusted as a length;
    anything but 12 or 24 word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
2026-11-11 Bootloader: release signing key and flash write protection
    The bootloader now checks firmware against the release LMS key, and
    it write-protects its own flash before starting the app, so a
    running firmware can no longer rewrite the bootloader or mark itself
    as official. Updates and the app settings page are not affected.
    - Release public key; SIGNATURES.md records every index used
    (index 0: bootloader test build)
    - Bootloader flash and boot flash locked until the next reset
    - The programming pass checks every HEX record again (audit L10)
    - Temporary BOOT_LOCK_TEST on the MCU serial screen, to remove
    after the device test
2026-11-11 Close the remaining security review findings
    The vault, the entropy sources and the PSBT review get the last
    fixes of the security review; only the device tests remain open.
    - Vault records take their nonce from an HMAC of the counter, the
    header and the text, so a rolled back header can no longer make
    a nonce repeat (M3); older records open as before
    - AUTO UNLOAD is on from the factory, 10 minutes (L11)
    - STOPWATCH hashes its timer samples and asks for twice the presses;
    POKER CARDS first explains that each card goes back into the deck
    (L4)
    - A PSBT without previous transactions gets a red warning before
    the confirmation and can still be signed (L9)
    - The temporary bootloader lo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
2026-11-12 Shrink interface code 5.4 KB and add a UR PSBT animator
    The interface files (menus, screens, PSBT review, descriptors, UR
    export, settings, decoy and the generated MCC files) get extra size
    options; cryptography and long operations keep the project options.
    - tools/ur_psbt_animator.html: offline page that shows a PSBT as an
    animated UR:CRYPTO-PSBT QR like Sparrow, with loss and mixed-only
    modes to test the fountain decoder, plus test PSBTs to paste
    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
2026-11-13 Add single sig nested segwit (BIP49)
    WALLET > CONFIG > SCRIPT NESTED SEGWIT now works for single sig: the
    m/49' account with its ypub, 3... addresses, address scan, and signing
    of P2SH-P2WPKH inputs with the change checked. A PSBT of the other
    script type is refused with "SWITCH TO NESTED / NATIVE SEGWIT".
    Signatures are byte-identical to the independent Python signer, also
    on the device.
    - Malicious corpus runs in a new nested mode
    - UR crypto-account as sh(wpkh()) for the ypub QR
    - Animator: nested test PSBT preset
    - Wallet menu: the script type line no longer flickers
2026-11-13 Add nested segwit multisig and harden the SD card flows
    Multisig with SCRIPT NESTED SEGWIT now works: the m/48'/0'/n'/1'
    account with its Ypub, sh(wsh()) descriptors (text, Coldcard file with
    Ypub keys, UR crypto-output, vault copies), and signing of P2SH-P2WSH
    inputs with change checked against every cosigner. A descriptor or
    PSBT of the other script type is refused with the reason. Signatures
    are byte-identical to the independent Python signer, also on the
    device.
    - Hostile PSBT test suite now also covers nested segwit multisig
    wallets, with and without descriptor
    - Vault opens the card again, so a card swapped after reading PSBTs
    works without a detour
    - INITIALIZE CARD and WIPE ALL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
